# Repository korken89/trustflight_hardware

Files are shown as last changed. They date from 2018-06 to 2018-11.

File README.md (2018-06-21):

# ThrustFlight hardware reference design

A small and simple flight controller to be used with the  [trustflight firmware](https://github.com/korken89/trustflight_firmware) flight controller firmware, which is focusing on safety by using the Rust programming language.

## License

The hardware is OSHW using the Cern-OHL license.

## Images

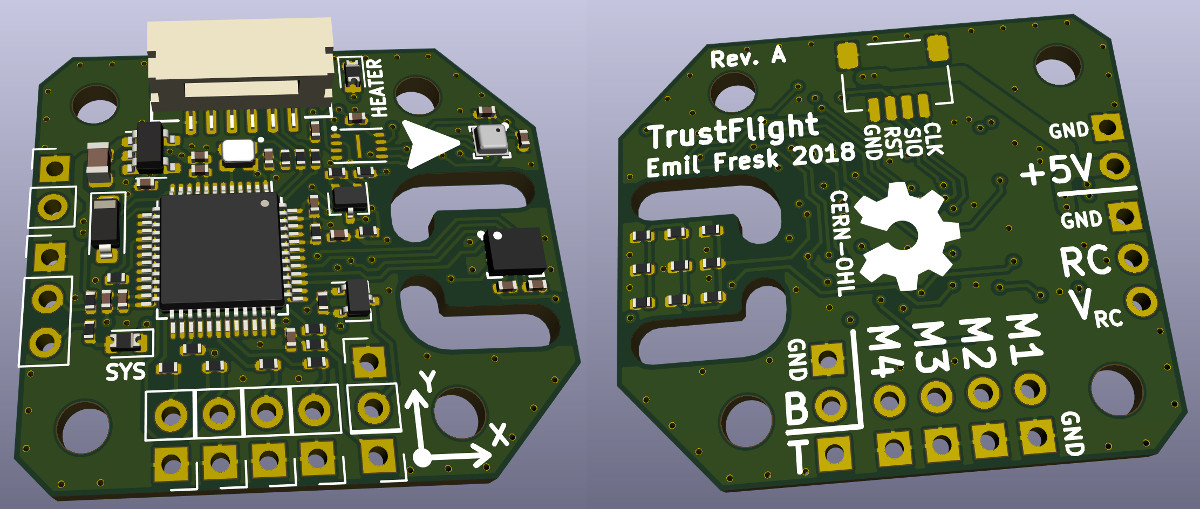
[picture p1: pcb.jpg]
PCV V1 RevA


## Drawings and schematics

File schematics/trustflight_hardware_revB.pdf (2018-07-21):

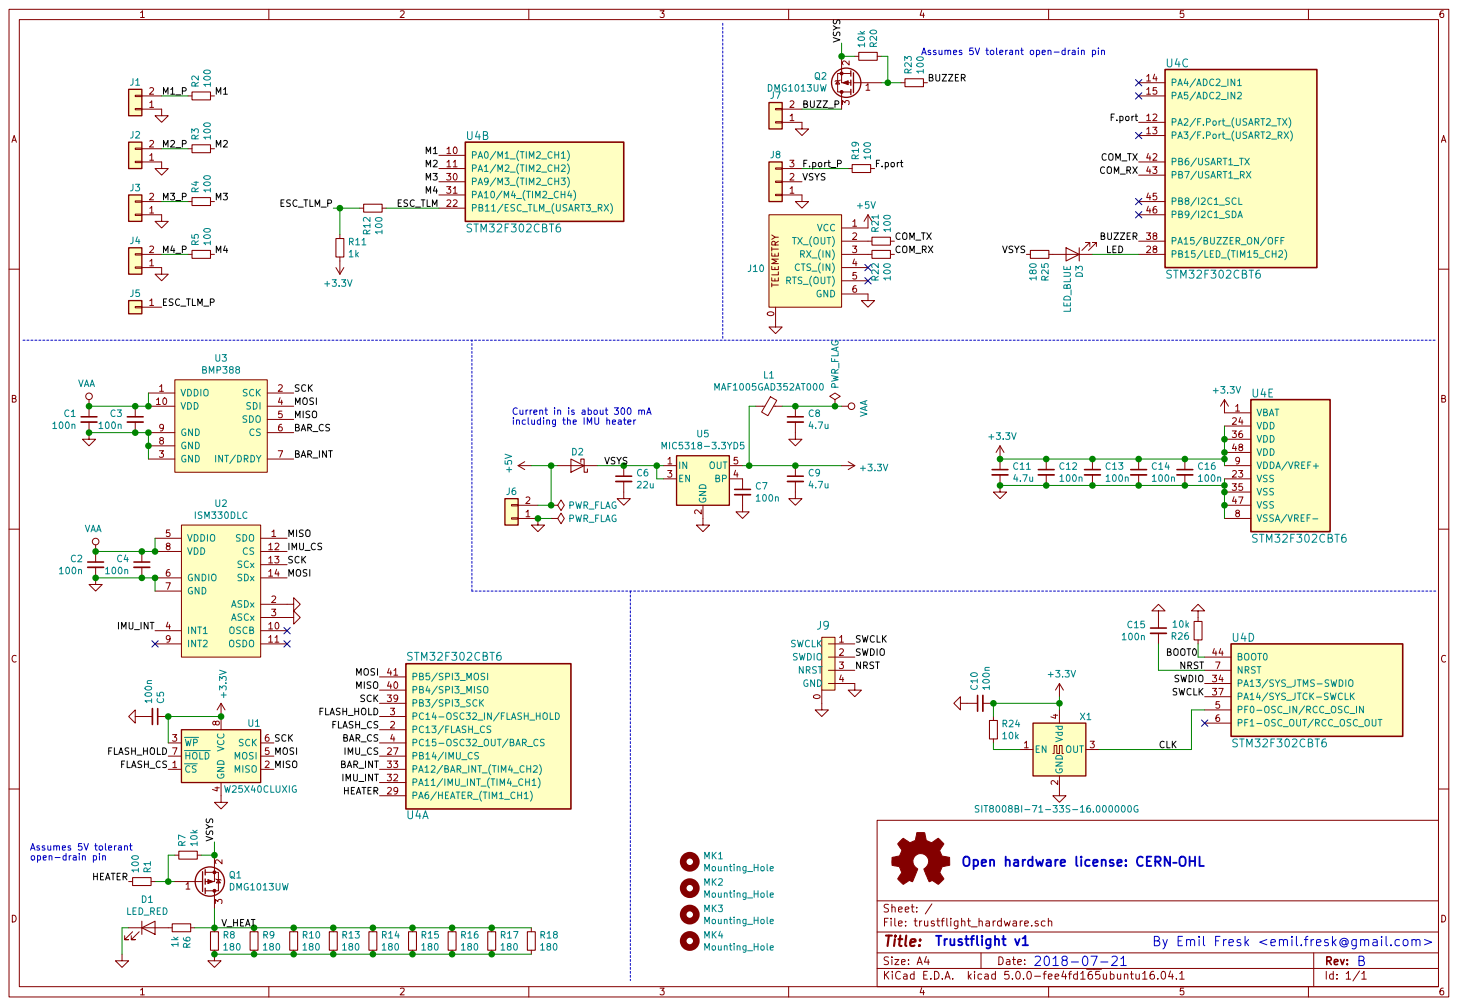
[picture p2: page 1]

Assumes 5V tolerant open-drain pin

STM32F302CBT6
IMU_INT HEATER MISO MOSI SCK MISO MOSI SCK

0 VCC 1 TX_(OUT) 2 RX_(IN) 3 CTS_(IN) 4 RTS_(OUT) 5 GND 6

Current in is about 300 mA

0 SWCLK 1 SWDIO 2 NRST 3 GND 4 J9 NRST SWDIO

4 MOSI 5 SCK 6 HOLD 7 VCC

Open hardware license: CERNOHL

By Emil Fresk <emil.fresk@gmail.com>

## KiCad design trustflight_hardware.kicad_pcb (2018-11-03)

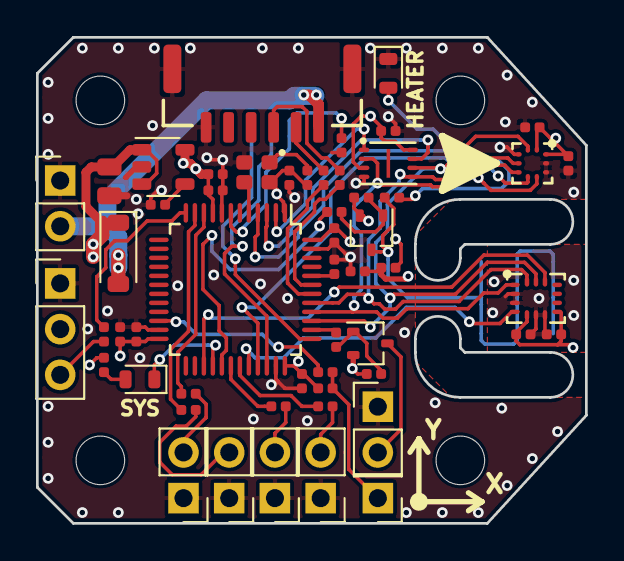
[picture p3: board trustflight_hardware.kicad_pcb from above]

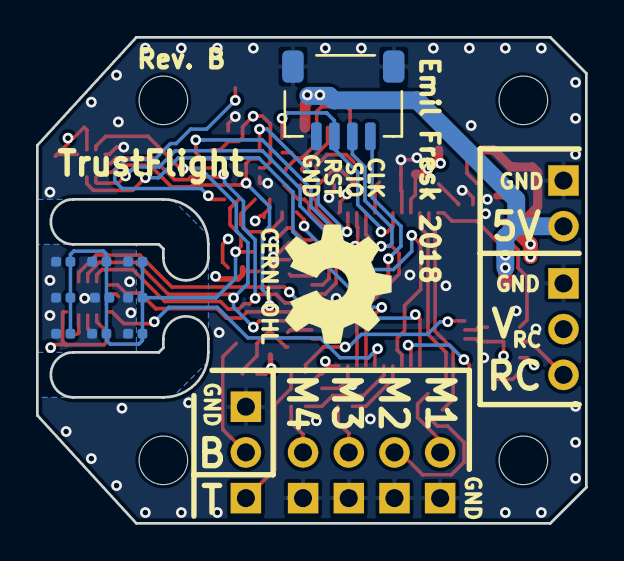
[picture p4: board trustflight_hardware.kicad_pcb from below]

Board: 4 copper layers, 30.5 x 27.0 mm, 69 parts (11 on the bottom side), 46 nets.

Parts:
C1, C2, C3, C4, C5, C7, C10, C12, C13, C14, C15, C16: 100n; C_0402_1005Metric_Rounded
C6: 22u; C_0805
C8, C9, C11: 4.7u; C_0402_1005Metric_Rounded
D1: LED_RED; D_0603_1608Metric_Rounded
D2: PMEG4005EGWX; D_SOD-123
D3: LED_BLUE; D_0603_1608Metric_Rounded
J1, J2, J3, J4, J6, J7: Conn_01x02; PinHeader_1x02_P2.54mm_Vertical
J5: Conn_01x01; PinHeader_1x01_P2.54mm_Vertical
J8: Conn_01x03; PinHeader_1x03_P2.54mm_Vertical
J9: swd-4; jst-sh-hor-4
J10: Dronecode_Telemetry; SM06B-GHS-TB
L1: MAF1005GAD352AT000; R_0402_1005Metric_Rounded
LOGO1: Logo_Open_Hardware_Small; OSHW-Symbol_6.7x6mm_SilkScreen
MK1, MK2, MK3, MK4: Mounting_Hole; MountingHole_2.7mm_M2.5
Q1, Q2: DMG1013UW; SOT-323_SC-70
R1, R2, R3, R4, R5, R12, R19, R21, R22, R23: 100; R_0402_1005Metric_Rounded
R6, R11: 1k; R_0402_1005Metric_Rounded
R7, R20, R24, R26: 10k; R_0402_1005Metric_Rounded
R8, R9, R10, R13, R14, R15, R16, R17, R18, R25: 180; R_0402_1005Metric_Rounded
U1: W25X40CLUXIG; USON-8-3x2mm-EP
U2: ISM330DLC; LGA-14-2.5x3
U3: BMP388; HLGA-10L-2.0x2.0-BMP388
U4: STM32F302CBT6; LQFP-48_7x7mm_Pitch0.5mm
U5: MIC5318-3.3YD5; SOT-23-5
X1: SIT8008BI-71-33S-16.000000G; Crystal_4Pin_2.0x1.6mm

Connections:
+3V3: C5.1, C9.1, C10.2, C11.1, C12.1, C13.1, C14.1, C16.1, L1.2, R11.2, R24.1, U1.3, U1.8, U4.1, U4.9, U4.24, U4.36, U4.48, U5.5, X1.4
+5V: D2.2, J6.2, J10.1
/BAR_CS: U3.6, U4.4
/BAR_INT: U3.7, U4.33
/BOOT0: R26.1, U4.44
/BUZZER: R23.2, U4.38
/BUZZ_P: J7.2, Q2.3
/CLK: U4.5, X1.3
/COM_RX: R22.2, U4.43
/COM_TX: R21.2, U4.42
/ESC_TLM: R12.2, U4.22
/ESC_TLM_P: J5.1, R11.1, R12.1
/F.port: R19.2, U4.12
/F.port_P: J8.3, R19.1
/FLASH_CS: U1.1, U4.2
/FLASH_HOLD: U1.7, U4.3
/HEATER: R1.2, U4.29
/IMU_CS: U2.12, U4.27
/IMU_INT: U2.4, U4.32
/LED: D3.1, U4.28
/M1: R2.2, U4.10
/M1_P: J1.2, R2.1
/M2: R3.2, U4.11
/M2_P: J2.2, R3.1
/M3: R4.2, U4.30
/M3_P: J3.2, R4.1
/M4: R5.2, U4.31
/M4_P: J4.2, R5.1
/MISO: U1.2, U2.1, U3.5, U4.40
/MOSI: U1.5, U2.14, U3.4, U4.41
/NRST: C15.2, J9.3, U4.7
/SCK: U1.6, U2.13, U3.2, U4.39
/SWCLK: J9.1, U4.37
/SWDIO: J9.2, U4.34
/VSYS: C6.1, D2.1, J8.2, Q1.2, Q2.2, R7.2, R20.2, R25.2, U5.1, U5.3
/V_HEAT: Q1.3, R6.1, R8.1, R9.1, R10.1, R13.1, R14.1, R15.1, R16.1, R17.1, R18.1
GND: C1.2, C2.2, C3.2, C4.2, C5.2, C6.2, C7.2, C8.2, C9.2, C10.1, C11.2, C12.2, C13.2, C14.2, C15.1, C16.2, D1.1, J1.1, J2.1, J3.1, J4.1, J6.1, J7.1, J8.1, J9.0, J9.4, J10.0, J10.6, R8.2, R9.2, R10.2, R13.2, R14.2, R15.2, R16.2, R17.2, R18.2, R26.2, U1.4, U2.2, U2.3, U2.6, U2.7, U3.3, U3.8, U3.9, U4.8, U4.23, U4.35, U4.47, U5.2, X1.2
unnamed: C7.1, U5.4
unnamed: D1.2, R6.2
unnamed: D3.2, R25.1
unnamed: J10.2, R21.1
unnamed: J10.3, R22.1
unnamed: Q1.1, R1.1, R7.1
unnamed: Q2.1, R20.1, R23.1
unnamed: R24.2, X1.1
VAA: C1.1, C2.1, C3.1, C4.1, C8.1, L1.1, U2.5, U2.8, U3.1, U3.10

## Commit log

2018-05-31 Most schematic done
    [trustflight_hardware.sch]
2018-06-03 Most of schematic done, started pcb
    [trustflight_hardware.kicad_pcb, trustflight_hardware.sch]
2018-06-04 All components on PCB, almost ready for routing
    [trustflight_hardware.kicad_pcb, trustflight_hardware.sch]
2018-06-04 Fixed VSYS
    [trustflight_hardware.kicad_pcb, trustflight_hardware.sch]
2018-06-06 Most of PCB routing is done
    [trustflight_hardware.kicad_pcb]
2018-06-07 No DRC errors, all routed
    [trustflight_hardware.kicad_pcb, trustflight_hardware.sch]
2018-06-07 Added silkscreen and some finishing touches
    [trustflight_hardware.kicad_pcb, trustflight_hardware.sch]
2018-06-07 More additions
    [trustflight_hardware.kicad_pcb, trustflight_hardware.sch]
2018-06-11 Updated values, shrunk copper planes under IMU
    [trustflight_hardware.kicad_pcb, trustflight_hardware.sch]
2018-06-25 Updated silkscreen
    [trustflight_hardware.kicad_pcb]
2018-07-21 Rev. B, fixed non 5V tolerant pins for heater/buzzer
    [trustflight_hardware.kicad_pcb, trustflight_hardware.sch]
2018-07-21 Added schematic plots
2018-11-03 Fixes for new KiCAD version and minor update to kicad_libs
    [trustflight_hardware.kicad_pcb, trustflight_hardware.sch]
